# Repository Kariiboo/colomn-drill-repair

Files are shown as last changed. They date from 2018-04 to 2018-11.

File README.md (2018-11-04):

# Colomn drilling machine safety cover support 3D model
  
> _[FR] Support de carter pour perceuse à colonne_

**License**: CC-BY-SA 4.0  This work is licensed under a [Creative Commons Attribution-ShareAlike 4.0 International License](http://creativecommons.org/licenses/by-sa/4.0)

**Disclaimer**: Use at your own risks

**[Link to fablab-lannion's wiki page](https://wiki.fablab-lannion.org//index.php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)**

## Description

This project is an OpenSCAD 3D model for a safety cover support of a colomn drilling machine. It suits the [FARtools P13E engine](http://www.perceuse-colonne.info/perceuse-a-colonne-fartools-one-p-13e/).

The original piece is build of ABS plastic. The conception of the colomn drilling machine involves plastic and metal pieces. Plastic is more fragile than metal and thus breaks easily under effort.

_**Note**: A possible corresponding piece for ~22,33€ (12,50€ + port) can be found here: [Protection-De-Mandrin-De-Rechange-Pour-AC13TP](http://www.worken.fr/p/120/Perceuse-a-colonne/Protection-De-Mandrin-De-Rechange-Pour-AC13TP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)_

## The 3D model picture
<figure>
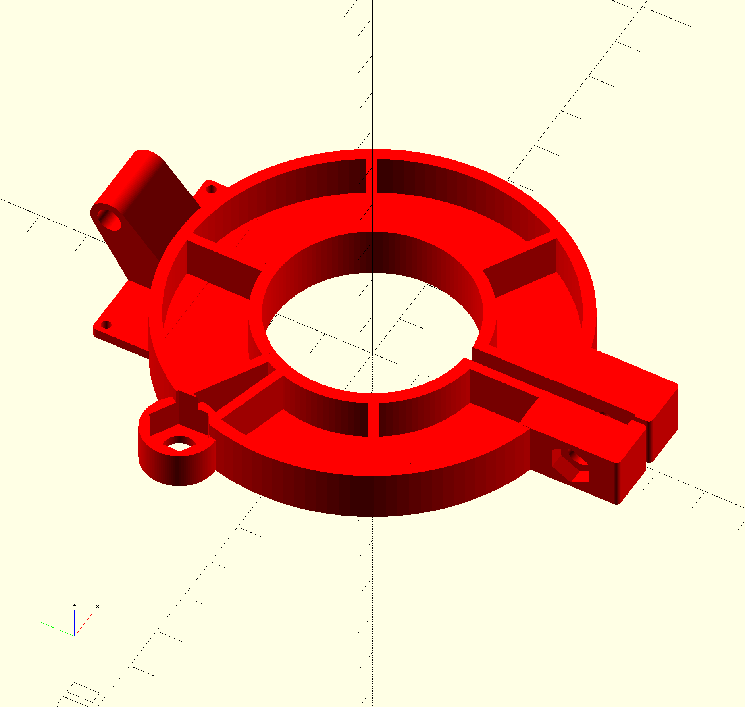
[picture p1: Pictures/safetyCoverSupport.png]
    
    <figcaption>Picture of the OpenSCASD 3D model</figcaption>
</figure>

## The repaired colomn drill
<figure>
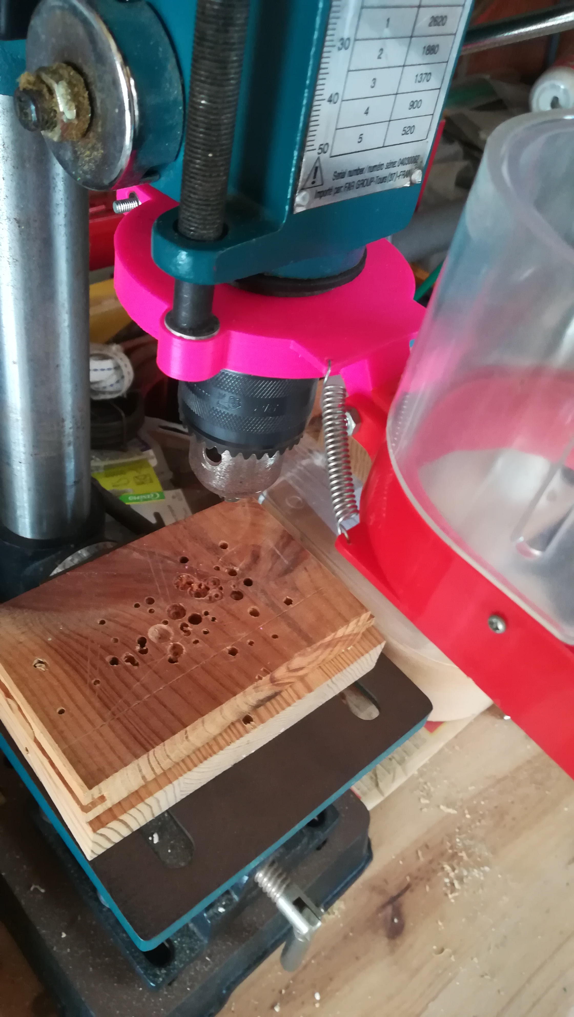
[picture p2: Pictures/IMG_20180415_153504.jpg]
    
    <figcaption>The repaired colomn drill</figcaption>
</figure>

## Other useful links

- About nut dimentions: https://fr.wikipedia.org/wiki/%C3%89crou_hexagonal

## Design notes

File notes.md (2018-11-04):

# Support de butée de profondeur pour perceuse à colonne

## Présentation

Ma perceuse à colonne [FARtools P13E engine](http://www.perceuse-colonne.info/perceuse-a-colonne-fartools-one-p-13e/) a une butée de profondeur métallique. Elle est fixée sur un support en plastique.
Le plastique est moins résistant que le métal et va casser tôt ou tard. C'est fait.

J'ai envisagé plusieurs possibilités pour réparer:

- Recoller le morceau cassé sur le support :
    J'ai essayé... mais pas comme il aurait fallu et ça n'a pas tenu... J'ai collé encore. C'est moche, mais ça tient pour le moment. Il faudra vite une autre solution.
- Racheter un support :
    Après tout, ce n'est qu'un bout de plastique. Mais il faut commander le support, le carter de protection en plexiglass, deux ressorts et des boulons. Le tout pour un peu plus de 22€ [ici](http://www.worken.fr/p/120/Perceuse-a-colonne/Protection-De-Mandrin-De-Rechange-Pour-AC13TP) (12,50€ + les frais de port). C'est acceptable, mais c'est un peu dommage de commander tout ça. Et en plus, ça recassera un jour.

- Refaire un support en plastique avec une imprimante 3D :
    Modéliser et imprimer uniquement la partie abîmée. Et en imprimer une autre quand elle cassera à nouveau. L'idée est belle.

## Matériel

- Il faudra utiliser une imprimante 3D. Il y en a au FabLab !

## Modélisation

La première idée a été d'utiliser le logiciel [SketchUp](https://www.sketchup.com) car il est assez intuitif. Il existe maintenant une [version gratuite en ligne](https://app.sketchup.com/app). La section 3.2 des [conditions d'utilisations](https://app.sketchup.com/tos.html) me conduit à chercher un autre outil.

Après une discussion avec Jérôme, ce sera finalement [OpenScad](www.openscad.org). Un logiciel libre qui se prend en main assez facilement grâce au [tutoriel sur le wiki du FabLab](https://wiki.fablab-lannion.org/index.php?title=OpenSCAD) !

Après avoir réalisé une première version du modèle 3D, je fais une vérification des dimensions. N'ayant pas trouvé d'outil de mesure dans OpenScad, j'exporte en format STL. J'importe ce fichier dans une ancienne version de Sketchup, et j'utilise l'outil de mesure de Sketchup. Cette vérification met en évidence une erreur d'échelle : la pièce est deux fois trop grande !

Une fois l'erreur corrigée, je peux imprimer. Mais avant, on regarde le modèle avec Manu qui me fait quelques remarques judicieuses. En particulier celle-ci: une partie du support original n'est pas utilisée. En la supprimant on gagnera en temps d'impression et en plastique. Bien vu !

Au final ça donne ça : OpenSCAD 3D model
Le source du fichier OpenScad est disponible sur GitHub 

    <REFERENCE GITHUB>

## Impression 3D

Les étapes de l'impression, avec l'aide des personnes du FabLab:
- Export STL
- Import dans l'outil pour faire le "tranchage" et export du fichier vers le logiciel d'impression
- Impression

Une fois le support imprimé, je constate que les écrous ne rentrent pas dans les emplacements prévus. En discutant, une solution est trouvée pour utiliser quand même la pièce imprimée (merci Bernard) : en chauffant un peu les écrous on devrait pouvoir les rentrer en force dans les emplacements ! Et ça le fait ! Encore bien vu !
J'ai tout de même agrandi les emplacements des écrous sur le modèle 3D pour les impressions futures !

## Conclusion

L'impression de la pièce en plastique ABS prend environ 2 heures, et il faut compter un peu plus de 5€.
Impossible de compter le temps passé sur ce projet, mais qu'importe au regard des apprentissages et des discussions générées.
C'est une belle aventure que de réparer de cette manière. Et le jour ou ce support cassera à nouveau, pas d'hésitation j'en imprime un autre.

## Evolutions possibles

Pourquoi pas : ajouter un éclairage dans ce support : 3 LEDs (3, pour limiter les ombres), une pile et un interrupteur.

## Bibliographie

- Une perceuse à colonne [FARtools P13E engine](http://www.perceuse-colonne.info/perceuse-a-colonne-fartools-one-p-13e/)

- [Protection de mandrin de rechange pour AC13TP](http://www.worken.fr/p/120/Perceuse-a-colonne/Protection-De-Mandrin-De-Rechange-Pour-AC13TP)

- Logiciel libre de modélisation paramétrique [OpenScad](www.openscad.org)

- [Tutoriel OpenScad - FabLab Lannion](https://wiki.fablab-lannion.org/index.php?title=OpenSCAD)

- A propos de la dimension des écrous: https://fr.wikipedia.org/wiki/%C3%89crou_hexagonal

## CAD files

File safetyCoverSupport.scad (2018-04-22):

/*
File : safetyCoverSupport.scad

Description:
[EN] Colomn drilling machine safety cover support
[FR] Support de carter pour perceuse à colonne

Author: Nicolas Moteau (nicolas.moteau@orange.fr)
Version: 0.0.4
License: [CC-BY-SA 4.0](https://creativecommons.org/licenses/by-sa/4.0/)
*/

// Precision
$fn = 120; // 1st print at 120.

// Model parameters (in mm)
innerDiam = 40.5;
outterDiam = 82;

bottomHeight = 2; // hauteur du fond

ringThick = 2.5; // épaisseur des bagues
ringHeight = 11; // hauteur des bagues

clampingOpenningWidth = 3; // largeur de la lumière de serrage
halfOpenningWidth = clampingOpenningWidth / 2;

innerReinforcementWidth = 2; // largeur des renforts interieurs

nutCageHeight = ringHeight - 3;
nutCageDiam = 15;
nutCageAngle = 65.66;
nutCageAngles = [/*-nutCageAngle,*/ nutCageAngle]; // negative is on the right, the only one needed is on the left
delta_angle = 8;
nutCageReinforcementAngles = [/*-(nutCageAngle + delta_angle),*/ nutCageAngle + delta_angle];

// 3D Model definition

/** A cube with rounded edged on X & Y */
module roundedCube(x=10, y=10, z=10, r=1, h=0.1) {
  minkowski() {
    cube([x-r, y-r, z]);
    cylinder(r=r,h=h);
  }
}

module smallTongue(x, y, z) {
  difference() {
    // languette à coins arrondis
    roundedCube(x, y, z, r=1, h=0.1);
    // trous pour les ressorts
    union() {
      translate([1, y-2, -1])
        cylinder(h=z+2, d=2);
      translate([x-2, y-2, -1])
        cylinder(h=z+2, d=2);
    }
  }
}

color("red")
difference() {

  union() {
    // bottom surface
    color("yellow") rotate_extrude()
      translate([innerDiam/2, 0])
        square([(outterDiam - innerDiam)/2, bottomHeight]);
    
    // outter ring
    color("blue") rotate_extrude()
      translate([outterDiam/2 - ringThick, 0])
        square([ringThick, ringHeight]);
    
    // inner ring
    color("blue") rotate_extrude()
      translate([innerDiam/2, 0])
        square([ringThick, ringHeight]);
    
    // small tongue as a cube
    x=42; y=12; z=2;
    color("orange")
    translate([-(x-1)/2, outterDiam/2 - y/2, 0])
      smallTongue(x, y, z);
      
    // inner reinforcements
    step = 360 / 6;
    color("red") for (a = [0:step:360]) {
      rotate([0, 0, a])
        translate([-innerReinforcementWidth/2, innerDiam/2 + ringThick/2, 0])
          cube([innerReinforcementWidth, (outterDiam - innerDiam)/2 - ringThick, ringHeight]);
    }
    color("red") for (a = nutCageReinforcementAngles) {
      rotate([0, 0, a])
        translate([0, innerDiam/2 + ringThick/2, 0])
          cube([innerReinforcementWidth, (outterDiam - innerDiam)/2  - ringThick, ringHeight]);
    }
    color("blue") translate([halfOpenningWidth, -outterDiam/2, 0])
      cube([innerReinforcementWidth, (outterDiam - innerDiam)/2, ringHeight]);
    color("blue") translate([-halfOpenningWidth-innerReinforcementWidth, -outterDiam/2, 0])
      cube([innerReinforcementWidth, (outterDiam - innerDiam)/2, ringHeight]);

    // nut M6 cages (cages pour écrou) part 1
    for (a = nutCageAngles) {
      rotate([0, 0, a]) {
        color("green")
          translate([0, outterDiam/2 + nutCageDiam/4 - 1, 0])
            cylinder(h = nutCageHeight, d = nutCageDiam);
      }
    }

    // clamping system screw support
    color("lightblue")
    translate([2, -outterDiam/2 - 20 + 4, 0])
      roundedCube(10, 20, ringHeight, 1, 0.1);
    color("lightblue")
    translate([-10, -outterDiam/2 - 20 + 4, 0])
      roundedCube(10, 20, ringHeight, 1, 0.1);

    // connection axle
    color("lightblue")
    hull() {
      translate([0, outterDiam/2 + 10, 16]) rotate(90, [0, 1, 0]) cylinder(h=15.5, d=8, center=true);
      translate([-15.5/2, outterDiam/2 - 1, 2]) cube([15.5, 7, 8], false);
    }
  }

  // Parts to remove
  union() {
    // clamping system ligth openning
    translate([-halfOpenningWidth, -outterDiam/2 - 13.5, -1])
      cube([clampingOpenningWidth, (outterDiam - innerDiam)/2 + 14, ringHeight + 2]);

    // clamping screw hole
    translate([0, -outterDiam/2 - 7, ringHeight/2])
      rotate(90, [0, 1, 0])
        cylinder(h=25, d=5, center=true);
    // clamping screw's M4 nut cage, prof 3 (e=8.08, https://fr.wikipedia.org/wiki/%C3%89crou_hexagonal)
    translate([-9.5, -outterDiam/2 - 7, ringHeight/2])
      rotate(90, [0, 1, 0])
        cylinder(h=3.5, d=9, center=true, $fn=6);

    // 2 x nut M6 cages (cages pour écrou) part 2: holes
    color("blue") for (a = nutCageAngles) {
      rotate([0, 0, a])
        translate([0, outterDiam/2 + nutCageDiam/4 -1, 0]) {
          translate([0, 0, bottomHeight])
            rotate([0, 0, 25])
            cylinder(h = ringHeight-bottomHeight + 1, d = 12.5, $fn=6); // cage écrou M6 (e=11.54, https://fr.wikipedia.org/wiki/%C3%89crou_hexagonal)
          translate([0, 0, -0.2])
            cylinder(h = bottomHeight + 0.3, d = 6.5); // hole
        }
    }

    // connection axle hole
    translate([0, outterDiam/2 + 10, 16]) rotate(90, [0, 1, 0]) cylinder(h=17, d=5, center=true);
  }
}

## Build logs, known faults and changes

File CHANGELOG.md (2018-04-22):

# Colomn drilling machine safety cover support Changelog

See the [README.md](README.md) file for a description of the project.

## About this file

All notable changes to this project will be documented in this file.
The format is based on [Keep a Changelog](http://keepachangelog.com/en/1.0.0/) and this project adheres to [Semantic Versioning](http://semver.org/spec/v2.0.0.html).

## [V0.0.4] - 2018-01-11 - 2nd printed version (on 2018-04-04)

### Changed

- M6 nut cages 
  - position as a parameter
  - reinforcement position as a parameter
  - reinforcement length shorten from & to middle of rings thick
- adjust innerDiam (+0.5mm) to ease installation
- adjust axle hole diam (+0.5mm)
- adjust axle support larg (-0.5mm)
- small tongue placement so that spring holes are symetricals 
- center inner reinforcement at 0°
- adjust & adapt nut cage heigth to let space for the spring
- adjust M6 nut cage hole diam (+0.5mm)
- adjust M6 nut cage diam (+0.5mm)
- adjust clamping system M4 nut cage diam (+0.9mm)

### Removed

- remove cages reinforcement position as a parameter

## [V0.0.3] - 2018-01-10 - 1st printed version

### Changed

- Fix M6 nut cage position

### Removed

- Remove one unused M6 nut cage

## [V0.0.2] - 2018-01-06

### Changed

- Fix bug size (was twice larger !)
  Check method: export STL + import in Sketchup, then use measure tool.

## [V0.0.1] - 2018-01-05

### Added

- connection axle between safety cover part and the support
- clamping system screw support with hole and M4 nut cage
- rounded ends on tongue (extremité arrondies sur languette)
- spring holes on tongue (trou ressorts sur languette)
- 2 M6 nut cages (cages pour écrou)
- inner reinforcements
- parameters for dimensions
- clamping system opening

## [V0.0.0] - 2017-12-20

### Added

- [x] main structure

<!-- ChangeLog template

## [Vx.y.z] - YYYY-MM-DD

### Added

 - ...

### Changed

- ...

### Removed

- ...
-->

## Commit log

2018-01-11 Colomn drilling machine safety cover support 3D model
    [safetyCoverSupport.scad]
2018-01-11 Ignore png & stl file
2018-01-11 Update version
    [safetyCoverSupport.scad]
2018-04-22 Update CHANGLOG after 2nd printout
2018-04-22 Switch Licence to CC-BY-SA 4.0
    [safetyCoverSupport.scad]
